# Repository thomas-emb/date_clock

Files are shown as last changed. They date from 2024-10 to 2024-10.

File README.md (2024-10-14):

# Date clock

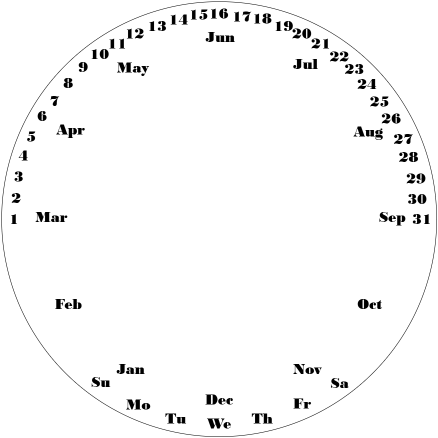
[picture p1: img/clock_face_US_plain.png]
a


This date clock aims to modify an existing analog quartz wall clock to render the date with its hands.

As clocks have three hands, a date clock allows for the rendering of three date properties:

* `hours` now displays the current month.
* `minutes` now displays the current day of the month.
* `seconds` now displays the current day of the week.

As weeks tend to start on either Sunday or Monday, dependent on the country,
this date clock uses day 0-6, where the meaning is entirely dependent on the face plate.

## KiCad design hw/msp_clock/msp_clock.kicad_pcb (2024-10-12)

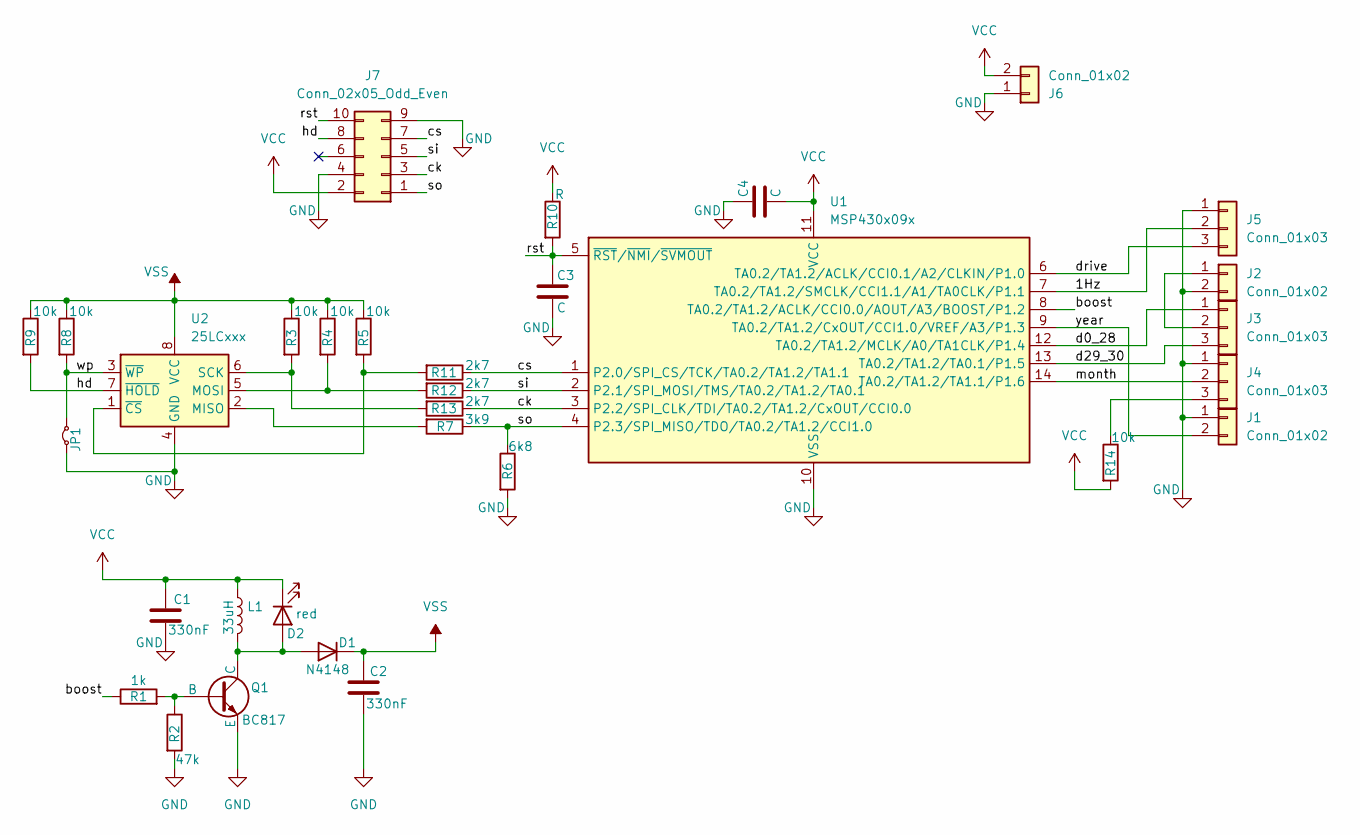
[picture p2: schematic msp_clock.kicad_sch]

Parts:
C1, C2: 330nF; C_0603_1608Metric_Pad1.08x0.95mm_HandSolder
C3, C4: C; C_0603_1608Metric_Pad1.08x0.95mm_HandSolder
D1: N4148; D_0603_1608Metric_Pad1.05x0.95mm_HandSolder
D2: red; LED_0603_1608Metric_Pad1.05x0.95mm_HandSolder
J1, J2, J6: Conn_01x02; PinHeader_1x02_P1.27mm_Vertical
J3, J4, J5: Conn_01x03; PinHeader_1x03_P1.27mm_Vertical
J7: Conn_02x05_Odd_Even; PinHeader_2x05_P1.27mm_Vertical
JP1: Jumper_2_Small_Bridged; R_0603_1608Metric_Pad0.98x0.95mm_HandSolder
L1: 33uH; L_Murata_LQH2MCNxxxx02_2.0x1.6mm
Q1: BC817; SOT-23-3
R1: 1k; R_0603_1608Metric_Pad0.98x0.95mm_HandSolder
R2: 47k; R_0603_1608Metric_Pad0.98x0.95mm_HandSolder
R3, R4, R5, R8, R9, R14: 10k; R_0603_1608Metric_Pad0.98x0.95mm_HandSolder
R6: 6k8; R_0603_1608Metric_Pad0.98x0.95mm_HandSolder
R7: 3k9; R_0603_1608Metric_Pad0.98x0.95mm_HandSolder
R10: R; R_0603_1608Metric_Pad0.98x0.95mm_HandSolder
R11, R12, R13: 2k7; R_0603_1608Metric_Pad0.98x0.95mm_HandSolder
U1: MSP430x09x; TSSOP-14_4.4x5mm_P0.65mm
U2: 25LCxxx; SOIC-8_3.9x4.9mm_P1.27mm

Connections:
/1Hz: J5.2, U1.7 (TA0.2/TA1.2/SMCLK/CCI1.1/A1/TA0CLK/P1.1)
/boost: R1.1, U1.8 (TA0.2/TA1.2/ACLK/CCI0.0/AOUT/A3/BOOST/P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)
/ck: J7.3, R13.1, U1.3 (P2.2/SPI_CLK/TDI/TA0.2/TA1.2/CxOUT/CCI0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)
/cs: J7.7, R11.1, U1.1 (P2.0/SPI_CS/TCK/TA0.2/TA1.2/TA1.1)
/d0_28: J3.1, U1.12 (TA0.2/TA1.2/MCLK/A0/TA1CLK/P1.4)
/d29_30: J3.3, U1.13 (TA0.2/TA1.2/TA0.1/P1.5)
/drive: J5.3, U1.6 (TA0.2/TA1.2/ACLK/CCI0.1/A2/CLKIN/P1.0)
/hd: J7.8, R9.2, U2.7 (~HOLD)
/month: J4.2, U1.14 (TA0.2/TA1.2/TA1.1/P1.6)
/rst: C3.1, J7.10, R10.2, U1.5 (~RST/~NMI/~SVMOUT)
/si: J7.5, R12.1, U1.2 (P2.1/SPI_MOSI/TMS/TA0.2/TA1.2/TA0.1)
/so: J7.1, R6.1, R7.1, U1.4 (P2.3/SPI_MISO/TDO/TA0.2/TA1.2/CCI1.0)
/wp: JP1.2 (B), R8.2, U2.3 (~WP)
/year: J1.2, U1.9 (TA0.2/TA1.2/CxOUT/CCI1.0/VREF/A3/P1.3)
GND: C1.2, C2.2, C3.2, C4.1, J1.1, J2.2, J4.1, J5.1, J6.1, J7.4, J7.9, JP1.1 (A), Q1.3 (E), R2.2, R6.2, U1.10 (VSS), U2.4 (GND)
unnamed: D1.2 (A), D2.2 (A), L1.2, Q1.1 (C)
unnamed: J2.1, J3.2
unnamed: J4.3, R14.1
unnamed: Q1.2 (B), R1.2, R2.1
unnamed: R7.2, U2.2 (MISO)
unnamed: R4.2, R12.2, U2.5 (MOSI)
unnamed: R3.2, R13.2, U2.6 (SCK)
unnamed: R5.2, R11.2, U2.1 (~CS)
VCC: C1.1, C4.2, D2.1 (K), J6.2, J7.2, L1.1, R10.1, R14.2, U1.11 (VCC)
VSS: C2.1, D1.1 (K), R3.1, R4.1, R5.1, R8.1, R9.1, U2.8 (VCC)

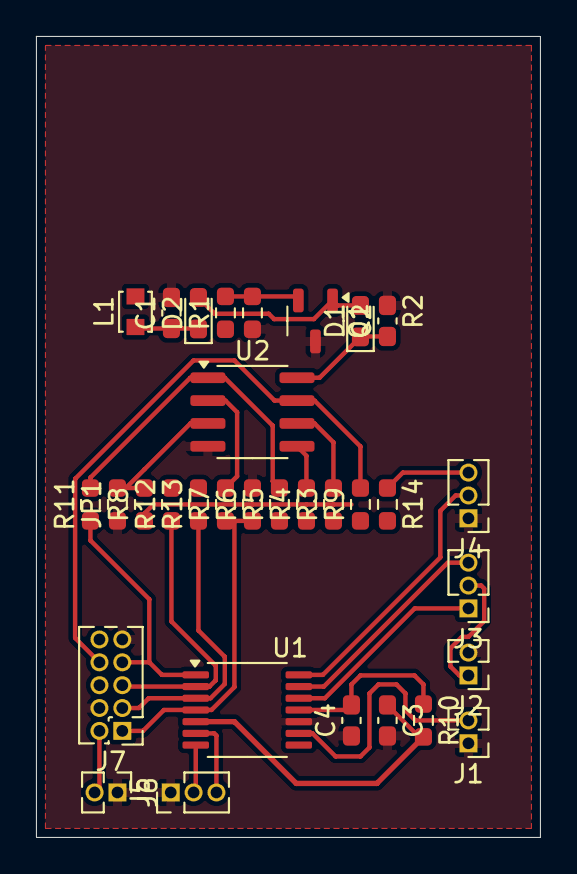
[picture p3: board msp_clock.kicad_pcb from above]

Board: 2 copper layers, 28.0 x 44.5 mm, 32 parts (0 on the bottom side), 25 nets.

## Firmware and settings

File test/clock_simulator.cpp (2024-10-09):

#include <algorithm>
#include <assert.h>
#include <vector>

#include "clock_simulator.hpp"

bool operator&(Pin left, Pin right)
{
    if ((left == High && right == Low) || (left == Low && right == High) || (left == HiZ && right == HiZ))
        throw exception();
    if (left == High || right == High) return true;
    if (left == Low || right == Low) return false;
    if ((left == PullDown && right == PullUp) || (left == PullUp && right == PullDown))
        throw exception();
    if (left == PullUp || right == PullUp) return true;
    if (left == PullDown || right == PullDown) return false;
    throw exception();
}

Clock::Clock(uint8_t hour, uint8_t min, uint8_t sec, uint8_t year)
: hands{hour, min, sec, year}
{
}

Clock::Clock(Month month, uint8_t day, uint8_t weekday, uint8_t year)
: hands{uint8_t((month + 7) % 12), uint8_t((day + 44) % 60), uint8_t(36 - (weekday * 2)), year}
{
}

Clock::operator string() const
{    
    static const array<string, 12> MonthString {
        "Jan", "Feb", "Mar", "Apr", "May", "Jun", "Jul", "Aug", "Sep", "Oct", "Nov", "Dec"
    };

    return
        to_string(((hands[M] + 44) % 60) - 28) + 
        " " + MonthString[(hands[H] + 5) % 12] + 
        ", day" + to_string((36 - hands[S])/2) + ((hands[S] % 2) ? ".5" : "") +
        (hands[Y]?" non-leap":" leap");
}

void Clock::tick()
{
    hands[S] = (hands[S] + 1) % 60;
    if (hands[S] == 0)
    {
        hands[M] = (hands[M] + 1) % 60;
        if (hands[M] == 30) // note: the hour hand [2] indicates closest hour, not digital time hour
        {
            hands[H] = (hands[H] + 1) % 12;
            if (hands[H] == 0)
                hands[Y] = (hands[Y] + 1) % 4;
        }
    }
}

Sensor Clock::sense(const Pin monthPin) const
{   /*
     * Encoder for day-of-month uses two contacts connected to a third contact that is on the week encoder,
     * the week encoder is closed on valid day of week positions, shorting to ground (false),
     * the day-of-month contacts are closed respectively on day 1-30 of the month and 29-31 of the month.
     * The month encoder is contacting to ground (false) for 31 day months, pulled up (true) for 30 day months,
     * and floating (exception) for February, the monthPin is logically combined with this pin;
     * February can be probed for by toggling the sense pin between pull-up and pull-down.
     * The year encoder is shorted to ground (false) for leap years.
     */
    Sensor result;
    vector<uint8_t> weekdays{24, 26, 28, 30, 32, 34, 36};
    bool weekday = std::find(weekdays.begin(), weekdays.end(), hands[S]) != weekdays.end();
    result.d1_30 = weekday && (hands[M] >= 45 || hands[M] <= 14);
    result.d_29_31 = weekday && (hands[M] >= 13 && hands[M] <= 15);
    result.m = monthPin & vector<Pin>{Low, High, High, Low, High, Low, High, High, HiZ, High, Low, High}[hands[H]];
    result.y = hands[Y] == 0;
    return result;
}

bool operator==(const Clock& left, const Clock& right)
{
    return left.hands == right.hands;
}

std::ostream& operator<<(std::ostream& stream, const Clock& clock)
{
    return stream << "["
        << int(clock.hands[0]) << ", "
        << int(clock.hands[1]) << ", "
        << int(clock.hands[2]) << ", "
        << int(clock.hands[3]) << "]";
}

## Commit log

2024-10-04 tests added for simulator and pin logic
2024-10-08 implement some happy flows for the clock, add simulator hour hand behaviour
2024-10-10 initial kicad_mod footprint generator
2024-10-11 fully parametrized generation of encoders
2024-10-12 added hardware designs
    [encoders.kicad_pcb, encoders.kicad_sch, msp_clock.kicad_pcb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]
2024-10-12 move encoder wheel generator to `hw/encoders`
2024-10-12 calculate *actual* spacing for encoders, and some refactoring
    [encoders.kicad_pcb]
2024-10-14 refactoring of encoders, updated PCB stackup, added face plates
    [encoders.kicad_pcb]
2024-10-17 Add regression testing for generated encoders
2024-10-17 change working directory for encoder test
2024-10-17 clean up rendering of coordinates in kicad_mod
    [encoders.kicad_pcb]
